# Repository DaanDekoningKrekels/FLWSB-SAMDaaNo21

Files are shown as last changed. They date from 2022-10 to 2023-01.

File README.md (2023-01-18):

# Flexible LoRaWAN Sensor Board SAMDaaNo21

Het FLWSB Main Board is een microcontroller bord gebaseerd op de ATSAM D21 in de vormfactor vergelijkbaar met een Arduino Nano. Het moet gemakkelijk zijn om dit bord in een breadboard te prikken en zo testen uit te voeren of schakelingen te bouwen. 

SAMDaaNo21

[PDF versie van de pinout diagram](./assets/SAMDaaNo21-pinout.pdf ':ignore')

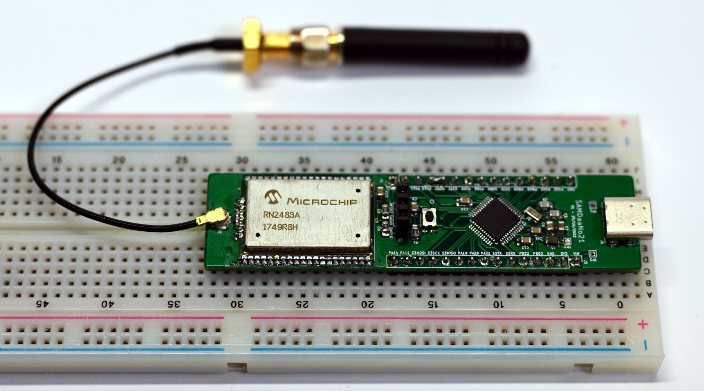
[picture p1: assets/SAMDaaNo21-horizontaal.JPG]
SAMDaaNo21-horizontaal


## KiCad bibliotheken

Het is handig om een printplaat te kunnen ontwikkelen waar de SAMDaaNo21 opgeprikt kan worden.

Om dit proces te vergemakkelijken is er een KiCad bibliotheek ontwikkeld, die bevat een symbol, footprint en 3D-model.

Het is aangeraden om bibliotheken die niet standaard in KiCad zitten mee in de projectmap te steken en te importeren als projectbibliotheek. Als je je projectmap dan deelt met derden zullen zij meteen beschikken over alle nodige bibliotheken.

Tutorial: [How to import into KiCad V6 & later?](https://support.snapeda.com/en/articles/5995733-how-to-import-into-kicad-v6-later)

[SAMDaaNo21 bibliotheek bestanden](https://github.com/Dacetylan/FLWSB/tree/SAMDaaNo21/src/printed-circuit-boards/FLWSB-SAMDaaNo21-KiCad-lib)

LWSB-SAMDaaNo21-v1-symbol SAMDaaNo21 symbol
LWSB-SAMDaaNo21-v1-footprint SAMDaaNo21 footprint

## Schema

Het elektrisch schema van dit bord ziet er als volgt uit:

Figuur 1: FLWSB-SAMDaaNo21 schema

Alle onderdelen worden verder toegelicht.

Figuur 2: Blokdiagram werking SAMDaaNo21

[ATSAM D21 Datasheet](https://ww1.microchip.com/downloads/en/DeviceDoc/SAM-D21DA1-Family-Data-Sheet-DS40001882G.pdf)

## Testpunten

Er zijn verschillende testpunten toegevoegd om op een gemakkelijke en toegankelijke manier verschillende parameters op het bord te kunnen meten.

Er is gekozen voor through hole testpunten zodat het gemakkelijk is om deze met een probe te meten. Alle testpunten zijn te vinden nabij de USB-poort.

| Testpunt nummer | Verbinding |
| --- | --- |
| TP1 | VBUS: 5 V afkomstig van USB |
| TP2 | VDD: 3,3 V gereguleerde spanning |
| TP3 | VIN: Ingangsspanning voordat het naar de lineaire regelaar gaat |

## LoRaWAN Module

Figuur 3: LoRaWAN module

Er is een RN2483 module mee geïmplementeerd op de printplaat. Deze is aangesloten op de UART bus van SERCOM 2.

De RN2483 bevindt zich aan het uiteinde. Er kan een antenne aangesloten worden via een U.FL connector.  

[Productpagina connector](https://be.farnell.com/hirose-hrs/u-fl-r-smt-1-10/rf-coaxial-u-fl-straight-jack/dp/1688077)

## USB Interface & VIN

Figuur 4: USB Interface & VIN schema

Het schema voor de USB-interface is gebaseerd op een voorbeeld uit een Atmel handleiding. De zener diodes die zichtbaar zijn zorgen ervoor dat de kans op schade door elektrostatische ontlading (ESD) beperkt wordt.

Figuur 5: USB Interface & VIN schema

[Ref USB-applications note](https://ww1.microchip.com/downloads/en/DeviceDoc/Atmel-42261-SAM-D21-USB_Application-Note_AT06475.pdf)

[Ref schematic checklist](https://ww1.microchip.com/downloads/en/DeviceDoc/SAM-D21DA1-Family-Data-Sheet-DS40001882G.pdf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)

De Schottky diode (D6) is er om de USB-poort van je laptop te beschermen wanneer het bord van stroom wordt voorzien via de VIN pin. Het zou kunnen dat aan de VIN pin een hogere spanning wordt geleverd dan 5 V waardoor dit potentiaalverschil ongewenste stroom kan laten vloeien. Hetzelfde principe wordt toegepast bij de ESP32 DEVKIT.

`TP3` is een testpunt dat aanwezig is om op een toegankelijke manier de VIN-spanning te meten.

[Ref ESP32 schema](https://dl.espressif.com/dl/schematics/esp32_devkitc_v4-sch-20180607a.pdf)

Het bordje kan voorzien worden van stroom via de USB-C poort. Een LDO (Low Dropout regelaar) zal de spanning afkomstig van de computer reguleren naar een stabiele 3,3 V.

De LDO is een LD1117S33 en ondersteunt een minimale ingangsspanning van 4,3 V en een maximale van 15 V. Dat kan worden aangelegd via de VIN pin. Er is een Schottky diode voorzien om ervoor te zorgen dat de spanning van VIN niet op de USB-poort komt te staan.

*Let op dat je met een lineaire regelaar te maken hebt. Hoe hoger de ingangsspanning, hoe warmer de LDO zal worden!*

Het is ook mogelijk om de regelaar over te slaan en rechtstreeks 3,3 V te leveren via de 3V3 pin. Dit kan handig zijn bij een situatie waarin we zo zuinig mogelijk willen zijn en een efficiëntere 3,3 V regelaar gebruiken van een andere pcb. *Belangrijk is dat deze spanning niet te hard mag afwijken van 3,3 V!*

## RESET & DEBUG

Figuur 6: RESET & DEBUG schema

De reset knop is opgebouwd zoals in de datasheet van de ATSAM D21 wordt weergegeven onder "Schematic Checklist Figure 45-4. External Reset Circuit Schematic".

Als er nog geen bootloader op de ATSAMD staat of als we een bare metal installatie gebruiken zullen we gebruik moeten maken van de program en debug header. Dat zijn de 3 pinnen centraal op de printplaat voor de LoRaWAN module. De pinout van links naar recht is: RESET, SWDIO, SWCLK. 

De ATSAMD maakt gebruik van Serial Wire Debugging (SWD), dat maakt het mogelijk om via fuses in te stellen, binaries in te laden en zelfs break-points aan je code toe te voegen.

## Low Dropout Lineair Regulator

Figuur 7: Low Dropout Lineair Regulator schema

In dit geval wordt er een LD1117 3,3 V regelaar gebruikt. Deze regelaar kan met een vrij groot ingangsbereik (tot 15 V) een uitgangsspanning van 3,3 V leveren.

`TP2` is een testpunt dat aanwezig is om op een toegankelijke manier de 3.3 V gereguleerde spanning te meten.

[LD1117 datasheet](https://www.st.com/resource/en/datasheet/ld1117.pdf)

## Power Supply Connections

Figuur 8: Power Supply Connections schema

Het schema voor de ontkoppelcondensatoren en spoel voor de ATSAM D21 komt ook rechtstreeks uit de datasheet. Wat belangrijk is bij deze componenten is dat alles rechts van de blauwe stippellijn zo dicht mogelijk bij de vermelde pinnen staat. Deze condensatoren vangen kleine storingen en rimpels op die zich voordoen in de bronspanning.

## Input / Output

Figuur 9: Input / Output schema

Dit zijn alle GPIO, SERCOM en power aansluitingen die via pinheaders naar buiten worden gebracht. De SERCOM poorten zijn alvast gedefinieerd zodat onder andere de pull-up weerstanden geplaatst kunnen worden. Alle andere poorten zijn voor algemeen gebruik. In de datasheet van de ATSAM D21 onder 7. I/O Multiplexing and Considerations kunnen alle verschillende mogelijkheden van deze aansluitingen gevonden worden (AC, ADC, DAC, PTC, DAC, IO, ...).

PA12 en PA13 zijn onderdeel van de I²C bus en hebben al een pull-up weerstand van 4,7 K voorzien. *Bij het plaatsen van nog externe pull-up weerstanden zullen zij in parallel staan en zal de weerstandswaarde te laag worden.*

| I/O Pin | Pin | SERCOM | SERCOM-ALT | External Interrupt | ADC, DAC, AC, REF | Peripheral Touch Controller | TC/TCC | TCC | COM | Generic Clock Generator |
| --- | --- | --- | --- | --- | --- | --- | --- | --- | --- | --- |
| GND | PowerPin | Ground Reference | | | | | | | | |
| PA02 | 3 | | | EXTINT:2 | ADC:0<br/>VOUT | Y:0 | | TCC3/<br/>WO:0 | | |
| PA03 | 4 | | | EXTINT:3 | ADC:1<br/>VREFA | Y:1 | | TCC3/<br/>WO:1 | | |
| PB08 | 7 | | SCOM4/<br/>PAD:0 | EXTINT:8 | ADC:2 | Y:14 | TC4/<br/>WO:0  | TCC3/<br/>WO:6 | | |
| PB09 | 8 | | SCOM4/<br/>PAD:1 | EXTINT:9 | ADC:3 | Y:15 | TC4/<br/>WO:1  | TCC3/<br/>WO:7 | | |
| PA04 | 9 | | SCOM0/<br/>PAD:0 | EXTINT:4 | ADC:4<br/>AC:0 VREFB | Y:2 | TCC0/<br/>WO:0 | TCC3/<br/>WO:2 | | |
| PA05 | 10 | | SCOM0/<br/>PAD:1 | EXTINT:5 | ADC:5<br/>AC:1 | Y:3 | TCC0/<br/>WO:1 | TCC3/<br/>WO:3 | | |
| PA06 | 11 | | SCOM0/<br/>PAD:2 | EXTINT:6 | ADC:6<br/>AC:2 | Y:4 | TCC1/<br/>WO:0 | TCC3/<br/>WO:4 | | |
| PA07 | 12 | | SCOM0/<br/>PAD:3 | EXTINT:7 | ADC:7<br/>AC:3 | Y:5 | TCC1/<br/>WO:1 | TCC3/<br/>WO:5 | I2S/<br/>SD:0 | |
| PA08 | 13 | SCOM0/<br/>PAD:0 | SCOM2/<br/>PAD:0 | NMI | ADC:16 | X:0 | TCC0/<br/>WO:0 | TCC1/<br/>WO:2 | I2S/<br/>SD:1 | |
| PA09 | 14 | SCOM0/<br/>PAD:1 | SCOM2/<br/>PAD:1 | EXTINT:9 | ADC:17 | X:1 | TCC0/<br/>WO:1 | TCC1/<br/>WO:3 | I2S/<br/>MCK:0 | |
| PA10 | 15 | SCOM0/<br/>PAD:2 | SCOM2/<br/>PAD:2 | EXTINT:10 | ADC:18 | X:2 | TCC1/<br/>WO:0 | TCC0/<br/>WO:2 | I2S/<br/>SCK:0 | GCLK:4 |
| PA11 | 16 | SCOM0/<br/>PAD:3 | SCOM2/<br/>PAD:3 | EXTINT:11 | ADC:19 | X:3 | TCC1/<br/>WO:1 | TCC0/<br/>WO:3 | I2S/<br/>FS:0 | GCLK:5 |
| PA12 | 21 | SCOM2/<br/>PAD:0 | SCOM4/<br/>PAD:0 | EXTINT:12 | AC:0 | | TCC2/<br/>WO:0 | TCC0/<br/>WO:6 | | |
| PA13 | 22 | SCOM2/<br/>PAD:1 | SCOM4/<br/>PAD:1 | EXTINT:13 | AC:1 | | TCC2/<br/>WO:1 | TCC0/<br/>WO:7 | | |
| VIN | PowerPin | LDL1117S33 4.3 V - 15 V | | | | | | | | |
| 3V3 | PowerPin | 3.3V LDO output | | | | | | | | |
| GND | PowerPin | Ground Reference | | | | | | | | |
| PB03 | 48 | | SCOM5/<br/>PAD:1 | EXTINT:3 | ADC:11 | Y:9 | TC6/<br/>WO:1  | TCC3/<br/>WO:3 | | |
| PB22 | 37 | | SCOM5/<br/>PAD:2 | EXTINT:6 | | | TC7/<br/>WO:0  | TCC3/<br/>WO:0 | | GCLK:0 |
| PA23 | 32 | SCOM3/<br/>PAD:1 | SCOM5/<br/>PAD:1 | EXTINT:7 | | X:11 | TC4/<br/>WO:0  | TCC0/<br/>WO:5 | USB/<br/>SOF 1KhZ | GCLK:7 |
| PA22 | 31 | SCOM3/<br/>PAD:0 | SCOM5/<br/>PAD:0 | EXTINT:6 | | X:10 | TC4/<br/>WO:1  | TCC0/<br/>WO:4 | | GCLK:6 |
| PA21 | 30 | SCOM5/<br/>PAD:3 | SCOM3/<br/>PAD:3 | EXTINT:5 | | X:9 | TC7/<br/>WO:1  | TCC0/<br/>WO:7 | I2S/<br/>FS:0 | GCLK:5 |
| PA20 | 29 | SCOM5/<br/>PAD:2 | SCOM3/<br/>PAD:2 | EXTINT:4 | | X:8 | TC7/<br/>WO:0  | TCC0/<br/>WO:6 | I2S/<br/>SCK:0 | GCLK:4 |
| PA19 | 28 | SCOM1/<br/>PAD:3 | SCOM3/<br/>PAD:3 | EXTINT:3 | AC:1 | X:7 | TC3/<br/>WO:1  | TCC0/<br/>WO:3 | I2S/<br/>SD:0 | |
| PA18 | 27 | SCOM1/<br/>PAD:2 | SCOM3/<br/>PAD:2 | EXTINT:2 | AC:0 | X:6 | TC3/<br/>WO:0  | TCC0/<br/>WO:2 | | |
| PA17 | 26 | SCOM1/<br/>PAD:1 | SCOM3/<br/>PAD:1 | EXTINT:1 | | X:5 | TCC2/<br/>WO:1 | TCC0/<br/>WO:7 | | GCLK:3 |
| PA16 | 25 | SCOM1/<br/>PAD:0 | SCOM3/<br/>PAD:0 | EXTINT:0 | | X:4 | TCC2/<br/>WO:0 | TCC0/<br/>WO:6 | | GCLK:2 |
| PA15 | 24 | SCOM2/<br/>PAD:3 | SCOM4/<br/>PAD:3 | EXTINT:15 | | | TC3/<br/>WO:1  | TCC0/<br/>WO:5 | | GCLK:1 |
| PA14 | 23 | SCOM2/<br/>PAD:2 | SCOM4/<br/>PAD:2 | EXTINT:14 | | | TC3/<br/>WO:0  | TCC0/<br/>WO:4 | | GCLK:0 |

### Legende

`SERCOM`: Serial Communication, keuze tussen: USART, I²C, SPI of SMBus

`EXTINT[n]`: External Interrupts

`AIN[n]`: ADC Analog Inputs

`X[n]`, `Y[n]`: Peripheral Touch Controller - PTC Input

`TC4/WO[n]`, `TC6/WO[n]`: Waveform/PWM Outputs

`TCC3/WO[n]`: Waveform/PWM Outputs/ Capture Inputs

`AC/CMP[n]`: AC Comparator Outputs

`I2S/FS[n]`: Inter-IC Sound Controller, I²S Word Select or TDM Frame Sync

`GCLK_IO[n]`: Generic Clock (source clock or generic clock generator output)

## Toekomstige verbeteringen

- Momenteel zijn er geen mounting holes aanwezig, dat vonden we  nog niet prioritair.
  - Mouning holes of inkepingen aan de randen van de printplaat zijn dus nog mogelijk en kunnen ook zeker van pas komen.
- De impedantie van het pad naar de antenne-aansluiting is niet theoretisch berekend. Dit is iets waar in een volgende versie over kan worden nagedacht.
- Er is geen LED aanwezig.
- Op het silkscreen staat een fout, `PA07` staat op het silkscreen als `PA09`. 
- Het schema bevat een fout die de LoRaWAN module onbruikbaar maakt. RX en TX van de UART-verbinding moeten omgewisseld worden.
  
### Tijdelijke oplossing LoRaWAN module

Een UART-verbinding heeft een TX (transmit) en RX (receive) aansluiting nodig. Logischerwijze zal je dus, bij een verbinding tussen twee apparaten, RX en TX met elkaar verbinden. Bij het ontwerpen van dit schema is door onoplettendheid TX met TX verbonden en RX met RX verbonden.

De PINMUX van de ATSAM D21 kan iedere SERCOM pin als RX instellen, maar niet iedere pin als TX schakelen. Dit maakt het onmogelijk om de oplossing geheel softwarematig te zoeken. Enkel PAD0 en PAD2 van een SERCOM poort kan je instellen als TX.

Wij hebben `PA8` (`S2TX` op het silkscreen) ingesteld als RX omdat deze verbonden is met de TX van de LoRaWAN module. `PA09` (`S2RX` op het silkscreen) hebben we hoog impedant gezet (`INPUT`) en kortgesloten met `PA10`. `PA10` is PAD2 van SERCOM2 dus kan ingesteld worden als nieuwe TX.

Het resultaat is dat we nu het baantje naar de RESET pin van de LoRaWAN module moeten onderbreken, omdat `PA10` verbonden is met deze pin. Die onderbreking is het gemakkelijkste te maken met een mesje of platte schroevendraaier net op de plek waar deze richting het pad van de module gaat.

De aanpassingen van deze pinnen is gemaakt in de ArduinoCore dus er hoeft in de code niets gewijzigd te worden.

Er is geen manier meer om de module te resetten vanaf de MCU, moest dat nodig zijn, dan kan er een kabeltje gesoldeerd worden naar een van de vrije GPIO pinnen.

## Bill of Materials

[Bill of materials ibom](./bom/ibom.html ':include :type=iframe width=100% height=1024px')

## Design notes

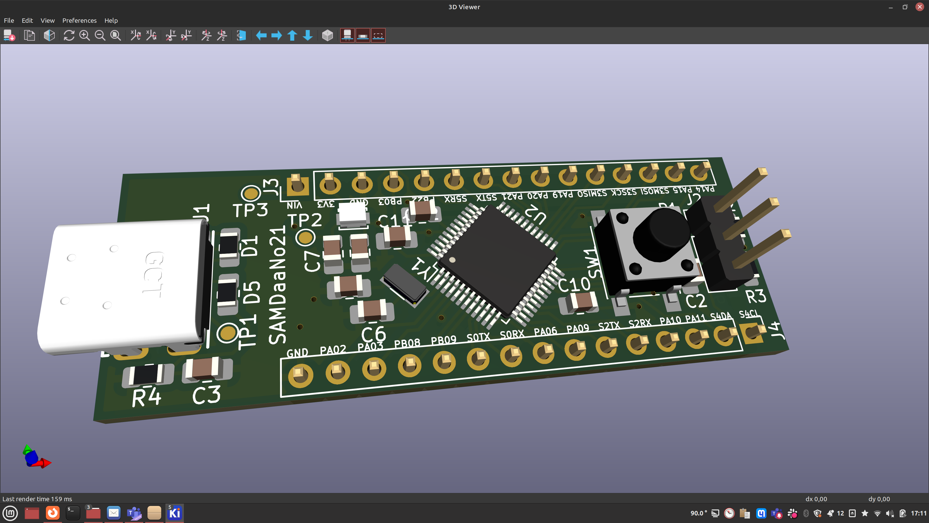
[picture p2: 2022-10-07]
assets/render.png

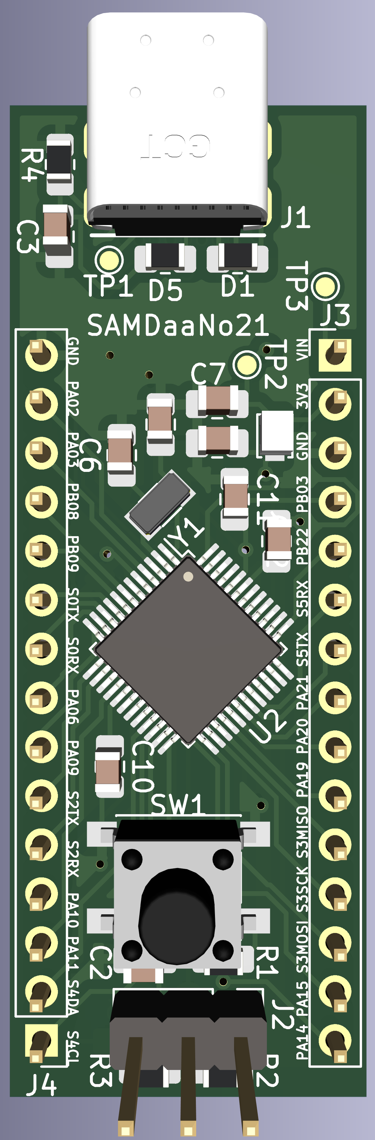
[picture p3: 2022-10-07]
assets/render-top.png

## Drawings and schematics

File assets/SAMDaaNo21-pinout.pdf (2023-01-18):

# SAMDaaNo21

# A SAMD21 Developmentboard withLoRaWAN

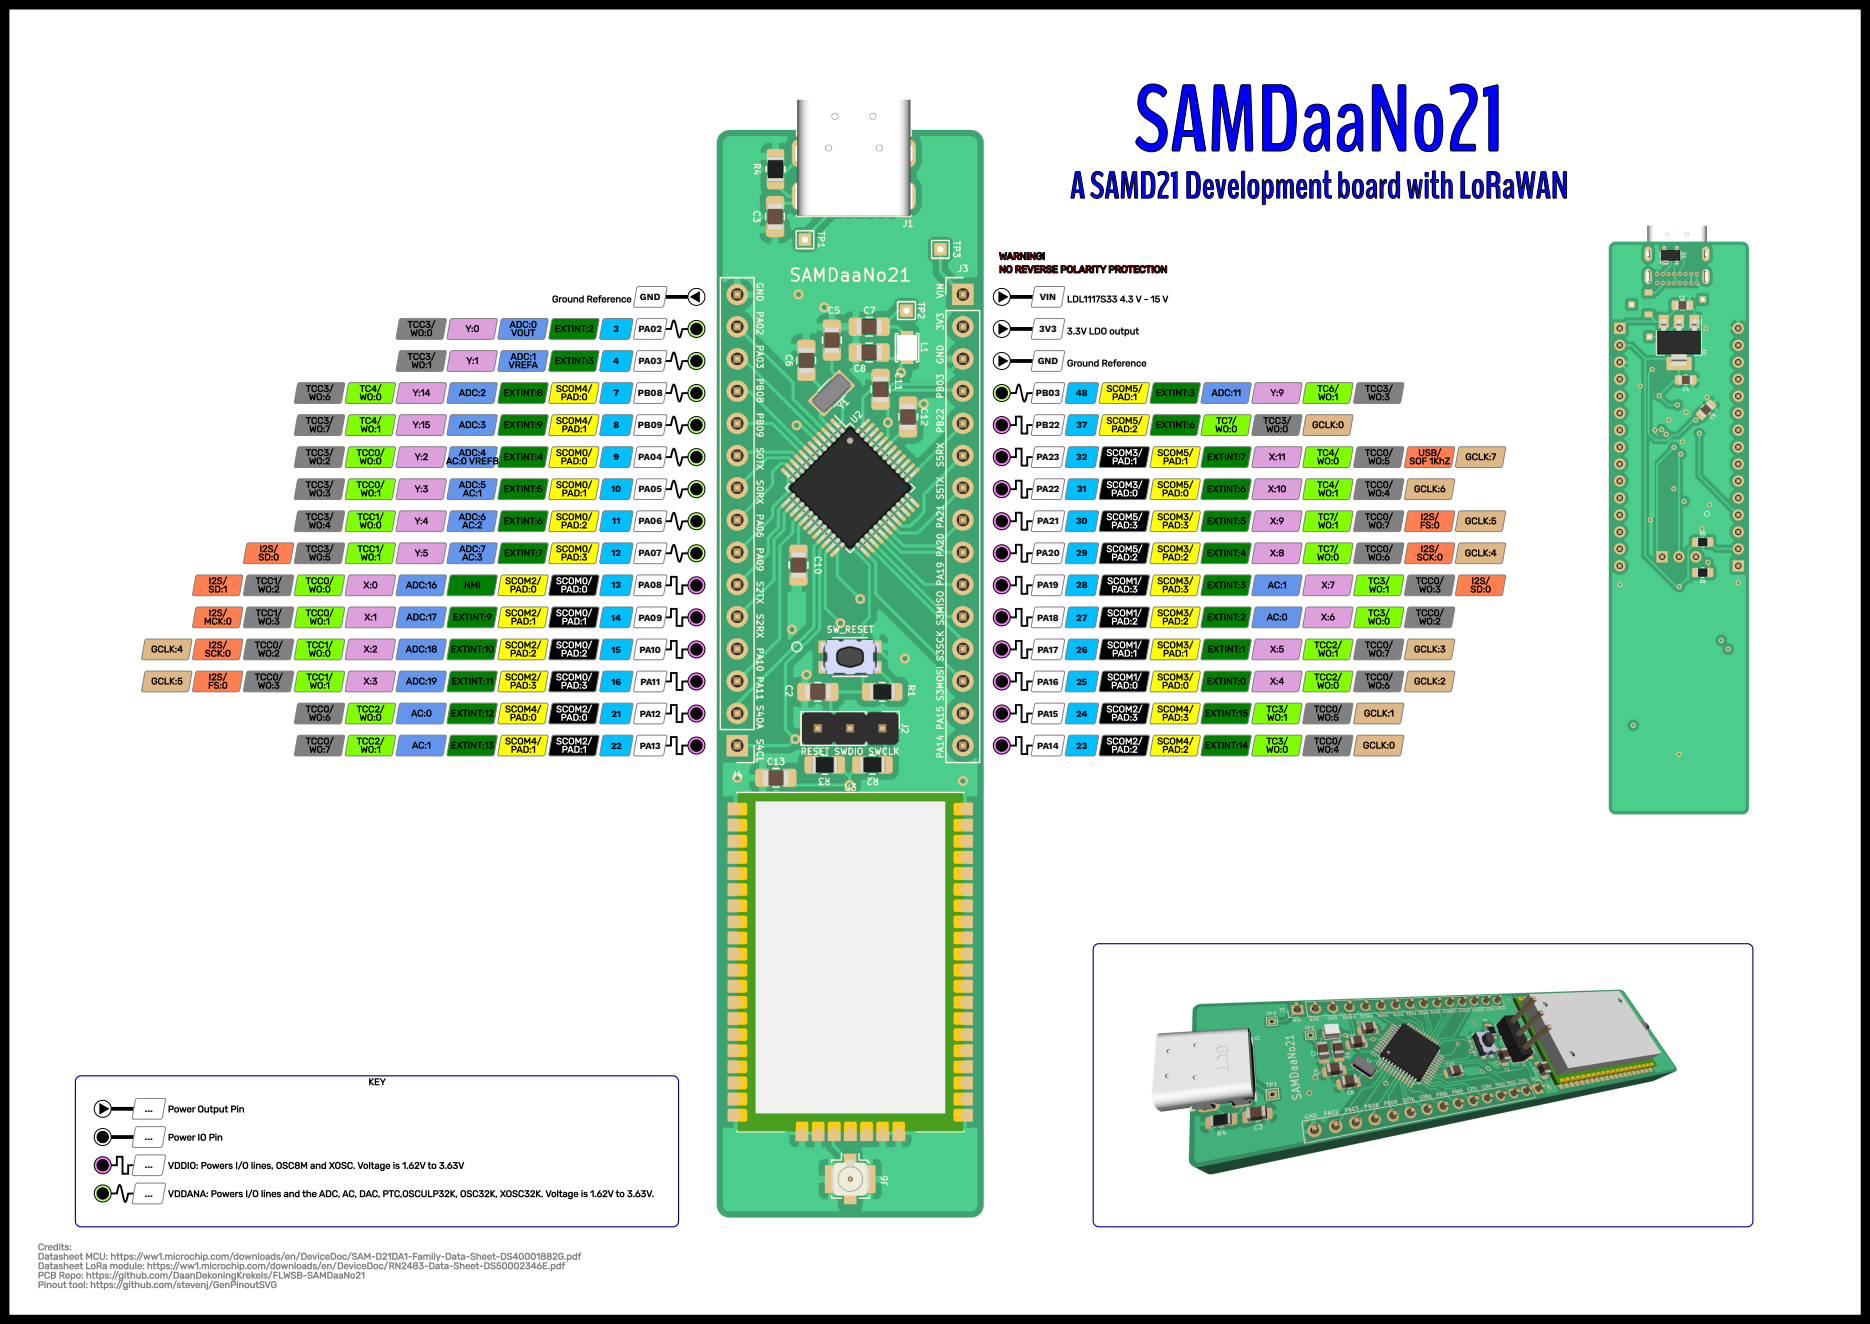
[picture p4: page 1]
EXTINT:2; PA02 ADC:0; VOUT; TCC3/ WO:0; EXTINT:3; PA03 ADC:1; VREFA; TCC3/ WO:1; SCOM4/ PAD:0; ADC:2; EXTINT:8; TCC3/ WO:6; SCOM4/ PAD:1; ADC:3; EXTINT:9; TCC3/ WO:7; SCOM0/ PAD:0; EXTINT:4 ADC:4 AC:0 VREFB; TCC0/ WO:0; TCC3/ WO:2; SCOM0/ PAD:1; EXTINT:5 ADC:5 AC:1; TCC0/ WO:1; TCC3/ WO:3; SCOM0/ PAD:2; EXTINT:6 ADC:6 AC:2; TCC1/ WO:0; TCC3/ WO:4; SCOM0/ PAD:3; EXTINT:7 ADC:7 AC:3; TCC1/ WO:1; TCC3/ WO:5; SCOM2/ PAD:0; ADC:16; NMI; TCC1/ WO:2; SCOM2/ PAD:1; ADC:17; TCC1/ WO:3; I2S/ MCK:0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

WARNING!
NO REVERSE POLARITY PROTECTION

Ground Reference GND

GND Ground Reference

Credits:
Datasheet MCU: https://ww1.microchip.com/downloads/en/DeviceDoc/SAM-D21DA1-Family-Data-Sheet-DS40001882G.pdf
Datasheet LoRa module: https://ww1.microchip.com/downloads/en/DeviceDoc/RN2483-Data-Sheet-DS50002346E.pdf
PCB Repo: https://github.com/DaanDekoningKrekels/FLWSB-SAMDaaNo21
Pinout tool: https://github.com/stevenj/GenPinoutSVG

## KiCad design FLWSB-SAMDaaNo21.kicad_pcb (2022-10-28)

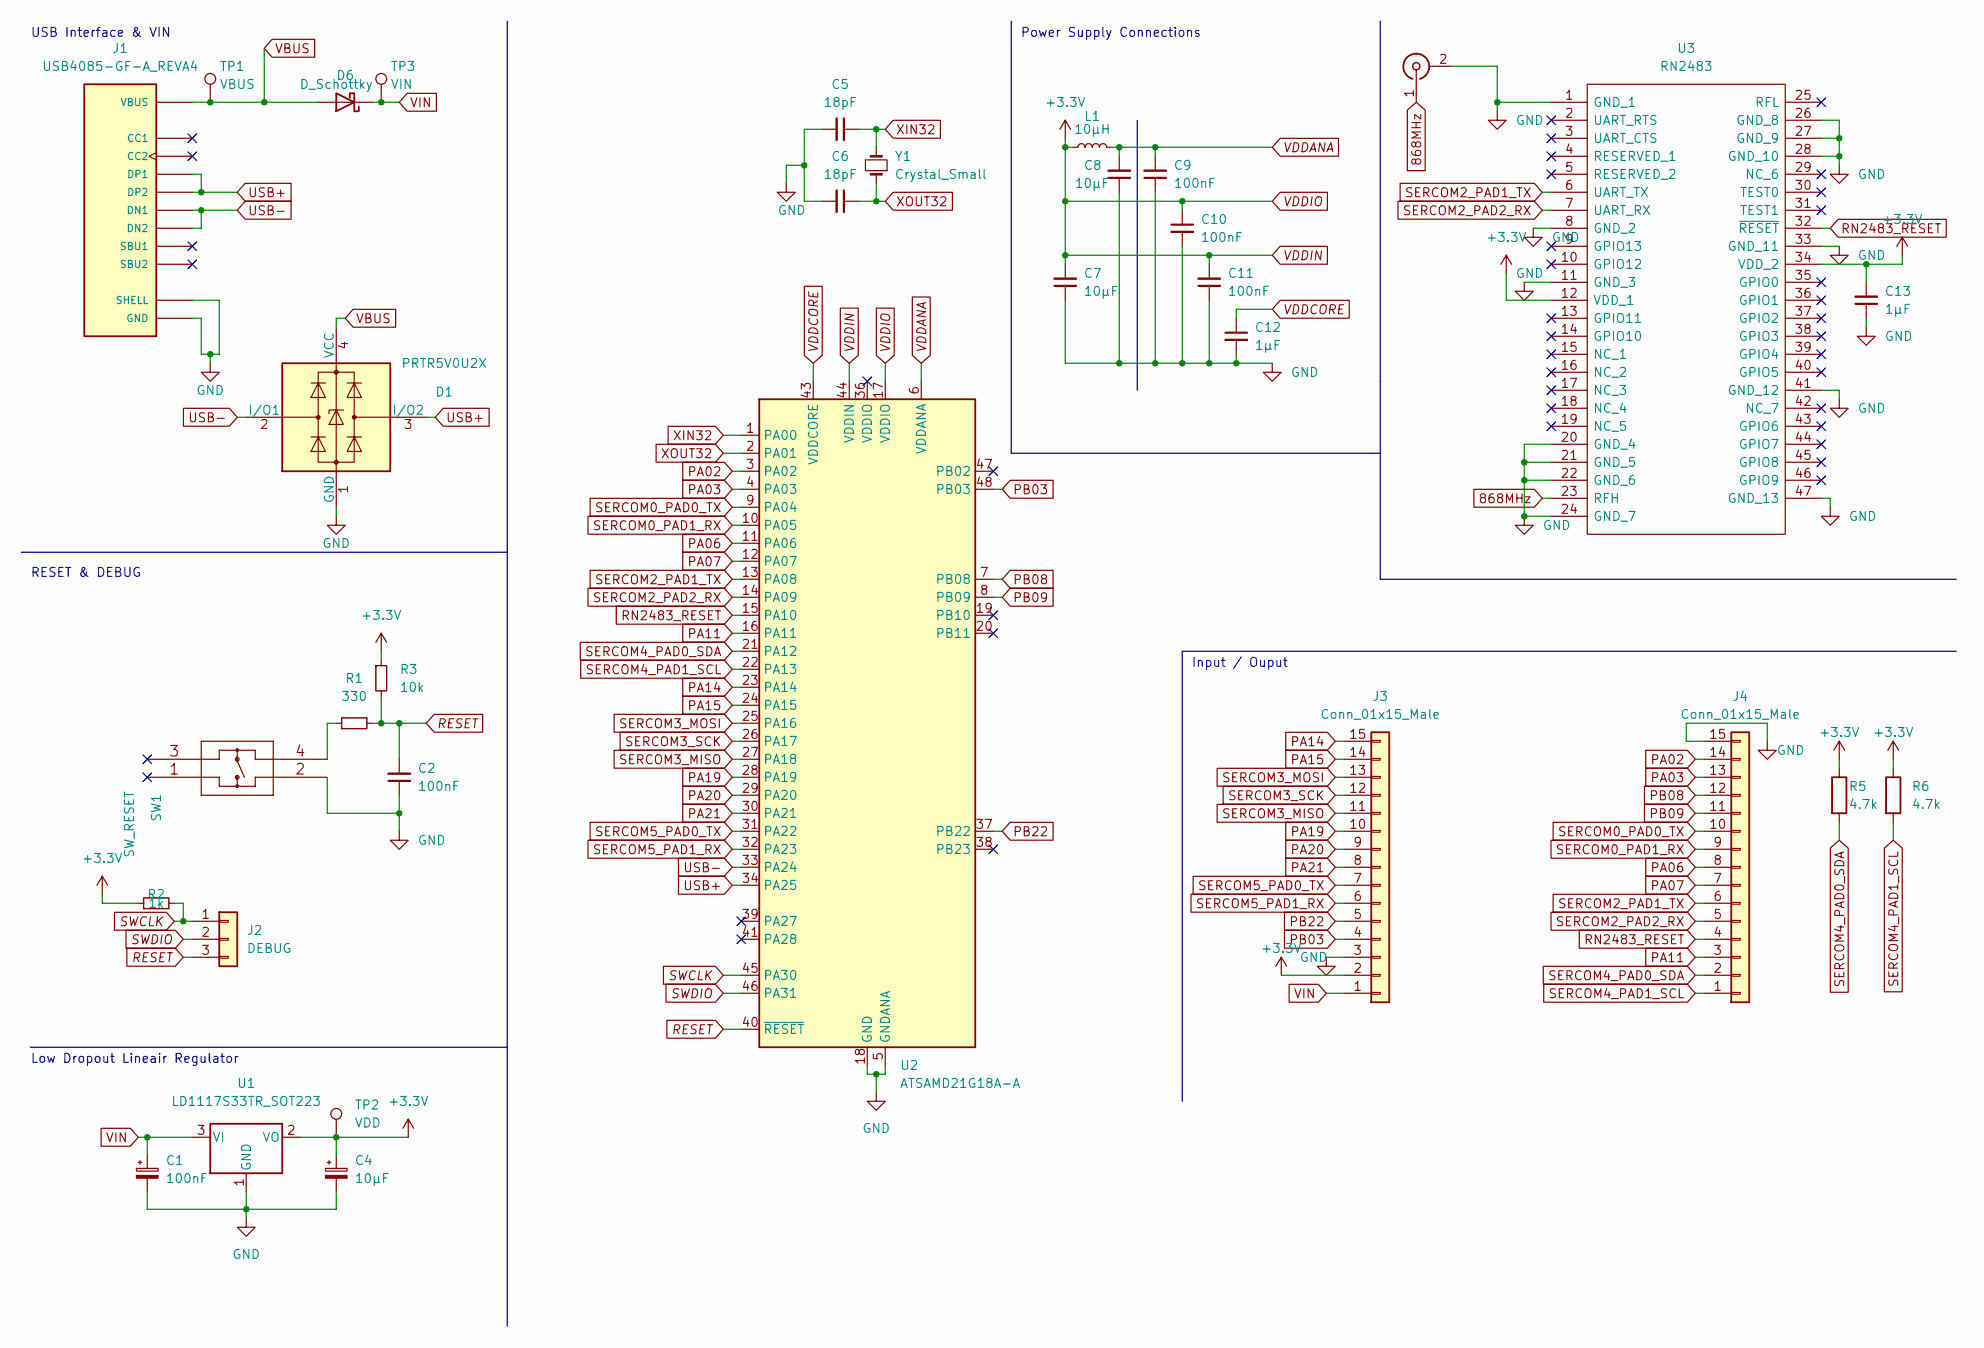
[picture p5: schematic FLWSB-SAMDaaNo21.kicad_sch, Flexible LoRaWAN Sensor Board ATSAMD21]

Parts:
C1, C2, C9, C10, C11: 100nF; C_0805_2012Metric_Pad1.18x1.45mm_HandSolder
C4, C7, C8: 10µF; C_0805_2012Metric_Pad1.18x1.45mm_HandSolder
C5, C6: 18pF; C_0805_2012Metric_Pad1.18x1.45mm_HandSolder
C12, C13: 1µF; C_0805_2012Metric_Pad1.18x1.45mm_HandSolder
D1: PRTR5V0U2X; SOT-143
D6: D_Schottky; SOD-123FL
J1: USB4085-GF-A_REVA4; GCT_USB4085-GF-A_REVA4; PARTREV A4
J2: DEBUG; PinHeader_1x03_P2.54mm_Vertical
J3, J4: Conn_01x15_Male; PinHeader_1x15_P2.54mm_Vertical
J6: Conn_Coaxial; U.FL_Molex_MCRF_73412-0110_Vertical
L1: 10µH; L_Murata_LQH2MCNxxxx02_2.0x1.6mm
R1: 330; R_0805_2012Metric_Pad1.20x1.40mm_HandSolder
R2: 1k; R_0805_2012Metric_Pad1.20x1.40mm_HandSolder
R3: 10k; R_0805_2012Metric_Pad1.20x1.40mm_HandSolder
R5, R6: 4.7k; R_0805_2012Metric_Pad1.20x1.40mm_HandSolder
SW1: SW_RESET; KMR7_CNK
TP1: VBUS; TestPoint_THTPad_1.0x1.0mm_Drill0.5mm
TP2: VDD; TestPoint_THTPad_1.0x1.0mm_Drill0.5mm
TP3: VIN; TestPoint_THTPad_1.0x1.0mm_Drill0.5mm
U1: LD1117S33TR_SOT223; SOT-223-3_TabPin2
U2: ATSAMD21G18A-A; TQFP-48_7x7mm_P0.5mm
U3: RN2483; Manufacturer_Part_Number RN2483
Y1: Crystal_Small; Crystal_SMD_3215-2Pin_3.2x1.5mm

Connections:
868MHz: J6.1 (In), U3.23 (RFH)
GND: C1.2, C2.1, C4.2, C5.2, C6.2, C7.1, C8.1, C9.1, C10.2, C11.1, C12.2, C13.1, D1.1 (GND), J1.A1 (GND), J1.A12 (GND), J1.B1 (GND), J1.B12 (GND), J1.P1 (SHELL), J1.P2 (SHELL), J1.P3 (SHELL), J1.P4 (SHELL), J3.3, J4.15, J6.2 (Ext), SW1.2, U1.1 (GND), U2.5 (GNDANA), U2.18 (GND), U2.35 (GND), U2.42 (GND), U3.1 (GND_1), U3.8 (GND_2), U3.11 (GND_3), U3.20 (GND_4), U3.21 (GND_5), U3.22 (GND_6), U3.24 (GND_7), U3.26 (GND_8), U3.27 (GND_9), U3.28 (GND_10), U3.33 (GND_11), U3.41 (GND_12), U3.47 (GND_13); also elsewhere on the board
unnamed: R1.1, SW1.4
PA02: J4.14, U2.3 (PA02)
PA03: J4.13, U2.4 (PA03)
PA06: J4.8, U2.11 (PA06)
PA07: J4.7, U2.12 (PA07)
PA11: J4.3, U2.16 (PA11)
PA14: J3.15, U2.23 (PA14)
PA15: J3.14, U2.24 (PA15)
PA19: J3.10, U2.28 (PA19)
PA20: J3.9, U2.29 (PA20)
PA21: J3.8, U2.30 (PA21)
PB03: J3.4, U2.48 (PB03)
PB08: J4.12, U2.7 (PB08)
PB09: J4.11, U2.8 (PB09)
PB22: J3.5, U2.37 (PB22)
RESET: C2.2, J2.3, R1.2, R3.2, U2.40 (~RESET)
RN2483_RESET: J4.4, U2.15 (PA10), U3.32 (~RESET)
SERCOM0_PAD0_TX: J4.10, U2.9 (PA04)
SERCOM0_PAD1_RX: J4.9, U2.10 (PA05)
SERCOM2_PAD1_TX: J4.6, U2.13 (PA08), U3.6 (UART_TX)
SERCOM2_PAD2_RX: J4.5, U2.14 (PA09), U3.7 (UART_RX)
SERCOM3_MISO: J3.11, U2.27 (PA18)
SERCOM3_MOSI: J3.13, U2.25 (PA16)
SERCOM3_SCK: J3.12, U2.26 (PA17)
SERCOM4_PAD0_SDA: J4.2, R5.2, U2.21 (PA12)
SERCOM4_PAD1_SCL: J4.1, R6.2, U2.22 (PA13)
SERCOM5_PAD0_TX: J3.7, U2.31 (PA22)
SERCOM5_PAD1_RX: J3.6, U2.32 (PA23)
SWCLK: J2.1, R2.2, U2.45 (PA30)
SWDIO: J2.2, U2.46 (PA31)
USB+: D1.3 (I/O2), J1.A6 (DP1), J1.B6 (DP2), U2.34 (PA25)
USB-: D1.2 (I/O1), J1.A7 (DN1), J1.B7 (DN2), U2.33 (PA24)
VBUS: D1.4 (VCC), D6.2 (A), J1.A4 (VBUS), J1.A9 (VBUS), J1.B4 (VBUS), J1.B9 (VBUS), TP1.1
VDDANA: C8.2, C9.2, L1.2, U2.6 (VDDANA)
VDDCORE: C12.1, U2.43 (VDDCORE)
VDDIN: C4.1, C7.2, C10.1, C11.2, C13.2, J3.2, L1.1, R2.1, R3.1, R5.1, R6.1, TP2.1, U1.2 (VO), U2.17 (VDDIO), U2.44 (VDDIN), U3.12 (VDD_1), U3.34 (VDD_2)
VIN: C1.1, D6.1 (K), J3.1, TP3.1, U1.3 (VI)
XIN32: C5.1, U2.1 (PA00), Y1.2; also elsewhere on the board
XOUT32: C6.1, U2.2 (PA01), Y1.1

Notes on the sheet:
Power Supply Connections
Input / Ouput
Low Dropout Lineair Regulator
RESET & DEBUG
USB Interface & VIN

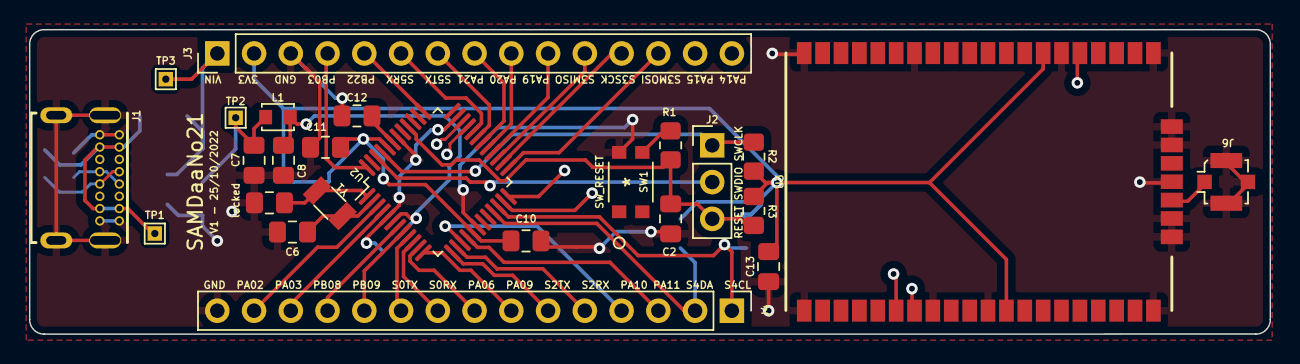
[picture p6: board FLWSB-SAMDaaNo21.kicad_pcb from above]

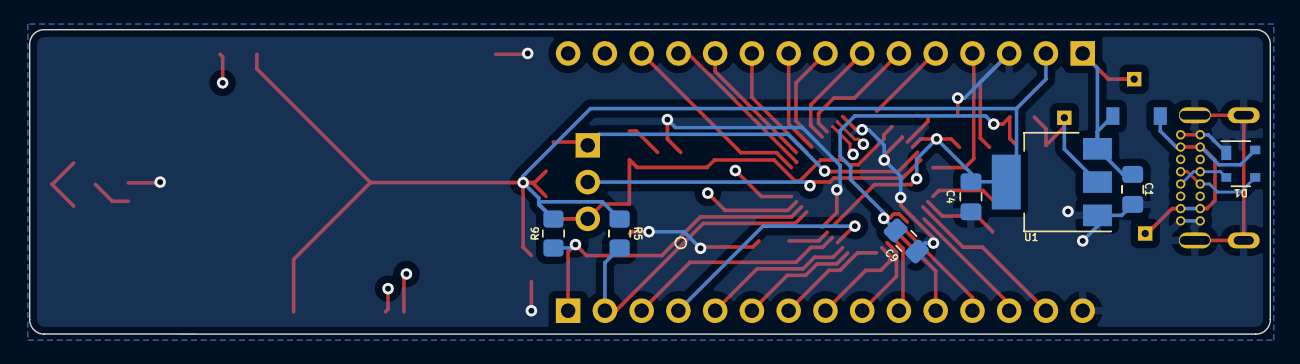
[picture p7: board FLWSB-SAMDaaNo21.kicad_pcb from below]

Board: 4 copper layers, 85.7 x 21.0 mm, 33 parts (8 on the bottom side), 41 nets.

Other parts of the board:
locked: 18pF; C_0805_2012Metric_Pad1.18x1.45mm_HandSolder

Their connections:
GND: locked.2; also elsewhere on the board
XIN32: locked.1; also elsewhere on the board

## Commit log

2022-09-23 Basis SAMDaaNo21 bord
    [FLWSB-SAMDaaNo21.kicad_pcb, FLWSB-SAMDaaNo21.kicad_sch]
2022-09-30 Schema zo goed als af
    [FLWSB-SAMDaaNo21.kicad_sch]
2022-10-07 PCB bijna af
    [FLWSB-SAMDaaNo21.kicad_pcb, FLWSB-SAMDaaNo21.kicad_sch]
2022-10-25 Laatste verbeteringen
    [FLWSB-SAMDaaNo21.kicad_pcb, FLWSB-SAMDaaNo21.kicad_sch]
2022-10-28 USB-C shell aan GND ipv R en C
    [FLWSB-SAMDaaNo21.kicad_pcb, FLWSB-SAMDaaNo21.kicad_sch]
2022-10-28 finale versie
    [FLWSB-SAMDaaNo21-B_Cu.gbl, FLWSB-SAMDaaNo21-B_Mask.gbs, FLWSB-SAMDaaNo21-B_Paste.gbp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]
2022-10-28 BOM in docs

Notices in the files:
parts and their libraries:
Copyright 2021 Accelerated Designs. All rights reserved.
